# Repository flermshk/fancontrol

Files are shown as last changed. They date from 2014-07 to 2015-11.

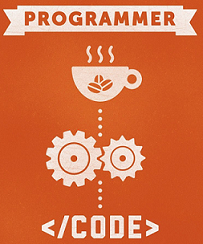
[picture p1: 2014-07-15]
Firmware/programmer-needs-coffee-to-code-hd-desktop-wallpaper.png

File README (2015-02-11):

---------------------------------------
BRIEF
The Project goal is to use a Attiny13A
and a temperature sensors to control
a PC fan.

A potentiometer is used to set the max
temperature at witch the fan are at
maximum capacity.

Under 25°C the fan stay off and the
power pin is also turned off.

Between 25°C and the max_temperature
the fan pwm folow a linear curve.

When selecting the max temperature
the led will blink for each 10°C
increment.

The pin refered as Reg_control or
power control is used to enable an step-up
power supply if no 12v is available.

---------------------------------------
PART REQUIREMENT

[Temperature IC]
Manufacturer: Texas Instrument
Part name	: LMT90DBZT
Footprint	: SOT23-3 / TO-236-3 / SC-59
Digi-Key	: 296-35732-1-ND
Price (x1)	: 1.18
Price (x10)	: 9.73
http://www.digikey.ca/product-search/en?KeyWords=296-35732-1-ND

[Micro-controler]
Manufacturer: Atmel
Part name	: ATTINY13A
Footprint	: 8-SOIC / 8-PDIP
Digi-Key	: ATTINY13A-SNRCT-ND / ATTINY13A-PU-ND
Price (x1)	: 1.66
Price (x10)	: 14.75
http://www.digikey.ca/product-detail/en/ATTINY13A-SNR/ATTINY13A-SNRCT-ND/3440990

---------------------------------------
ATTiny13A PINOUT
						  ___
(PCINT5/RST/ADC0/dW) PB5-|*	 |-VCC	[2:5] V.
(PCINT3/CLKI/ADC3)	 PB3-|	 |-PB2	(SCK/ADC1/T0/PCINT2)
(PCINT4/ADC2)		 PB4-|	 |-PB1	(MISO/AIN1/OC0B/INT0/PCINT1)
					 GND-|___|-PB0	(MOSI/AIN0/OC0A/PCINT0)
memory:
	1KB Flash
	64B SRAM
	64B EEMPROM

---------------------------------------
DESCRIPTION

Port	Tris		- ALT	- Role
- - - - - - - - - - - - - -
PB0	 - Output	- OC0A	- PWM (fan control)
PB1	 - Output	-		- Reg_control (on/off)
PB2	 - Output	-		- LED (alarm)
PB3	 -			- ADC3	- potentiometer
PB4	 -			- ADC2	- temp sensor
PB5	 - 			- dont	- touch

---------------------------------------
ABOUT
Author: Jonathan.L
Contributor: Laurence.DV

Original 14/06/2014
Update	25/07/2014

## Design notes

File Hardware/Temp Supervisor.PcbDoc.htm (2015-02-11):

Altium Reporting Options

# File in Newer Format

Date | : | 05/09/2014
Time | : | 19:48:47
Filename | : | C:\work\fancontrol\Hardware\Temp Supervisor.PcbDoc

Version | Warning
Release 10 update 1 | CAUTION - New Clearance Rule subscopes targeting differential pairs were introduced. Be aware that your design might contain Clearance Rules using those subscopes that cannot be read in previous versions.
Release 10 update 15 | CAUTION - Support of Solder Mask and Paste Mask expansions for Tracks, Arcs, Fills and Regions was introduced. Be aware that your design might contain Solder Mask and Paste Mask expansions for these types of primitives that cannot be read in the version of Altium Designer you are currently using.
Altium Designer update 19 | CAUTION - Air Gap Width attribute was introduced to Polygon Connect Style Rule. Be aware that your design might contain Polygon Connect Style Rules with new Air Gap Width attribute cannot be read in the version of Altium Designer you are currently using.
Release 13 | CAUTION - Silk To Solder Mask Clearance Rules are converted to Silkscreen Over Component Pads Rules.

This file was generated by a later version of the software

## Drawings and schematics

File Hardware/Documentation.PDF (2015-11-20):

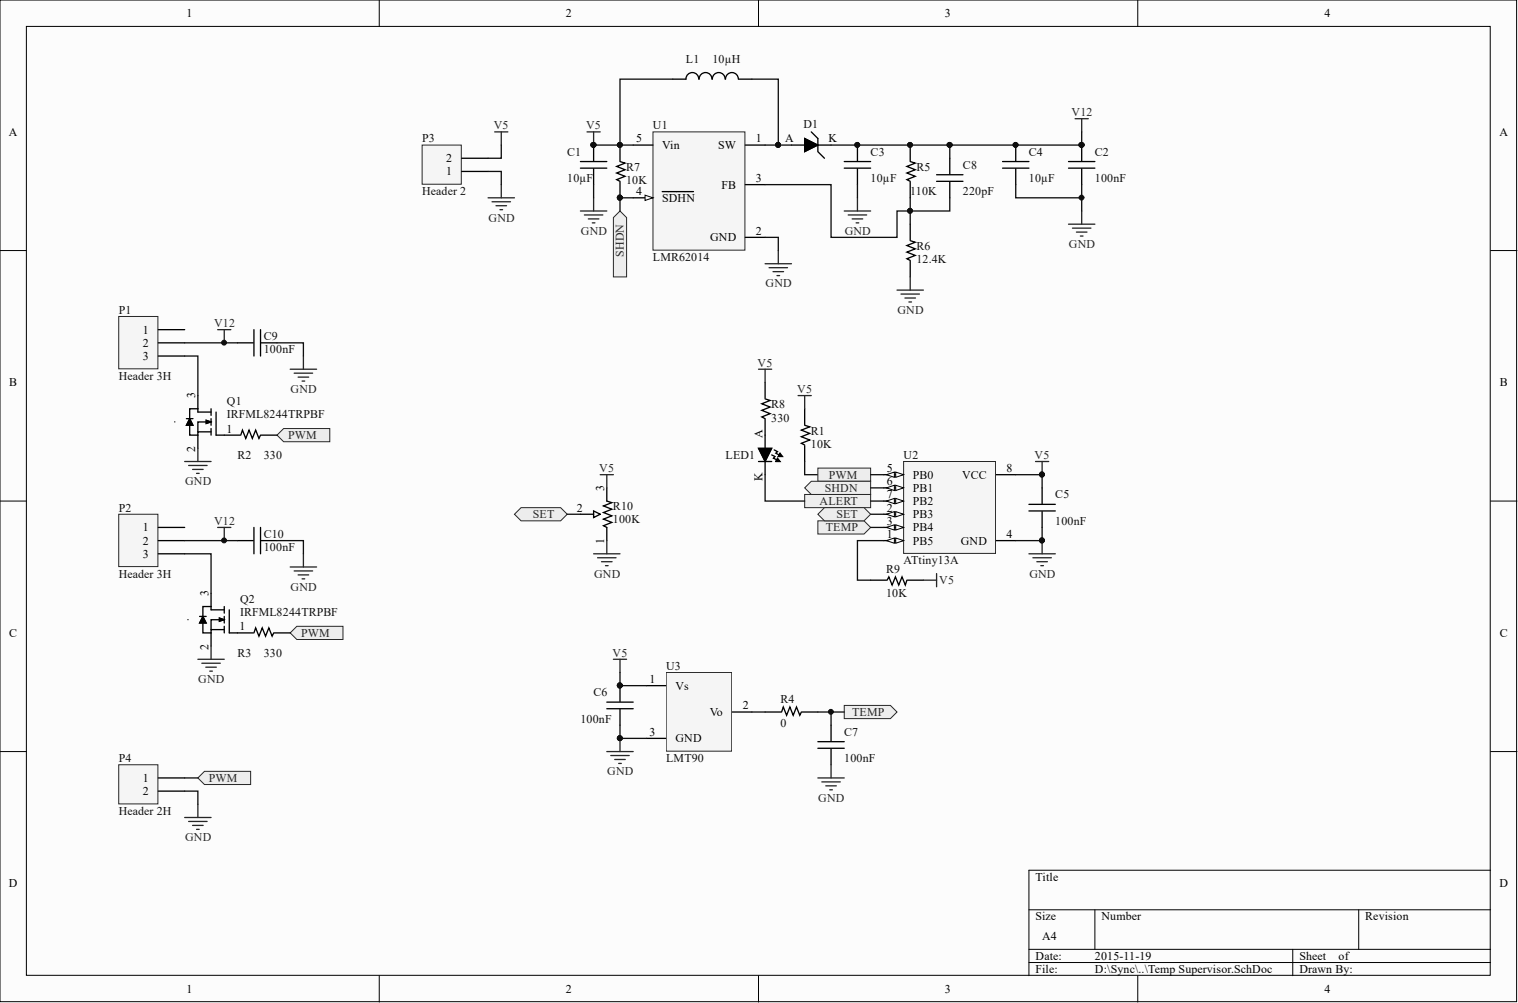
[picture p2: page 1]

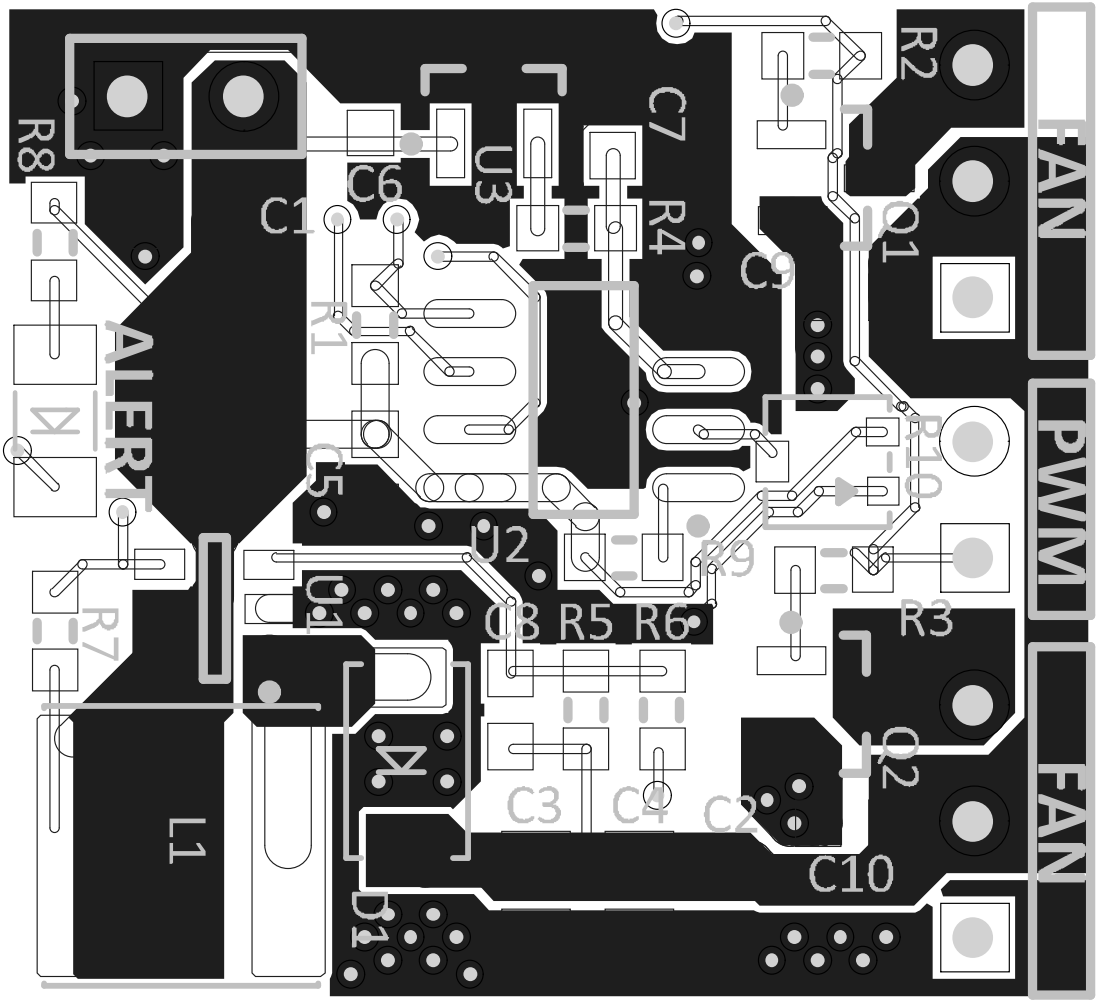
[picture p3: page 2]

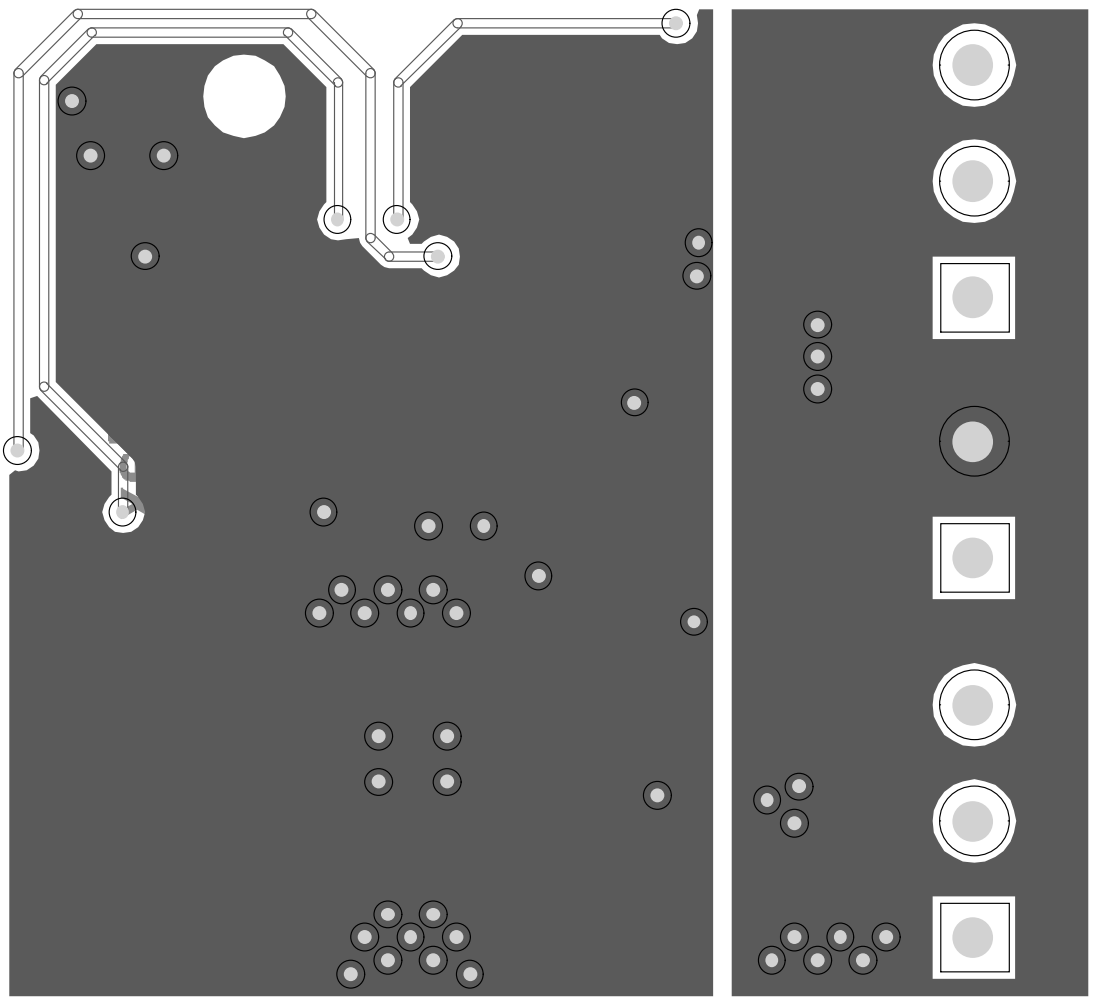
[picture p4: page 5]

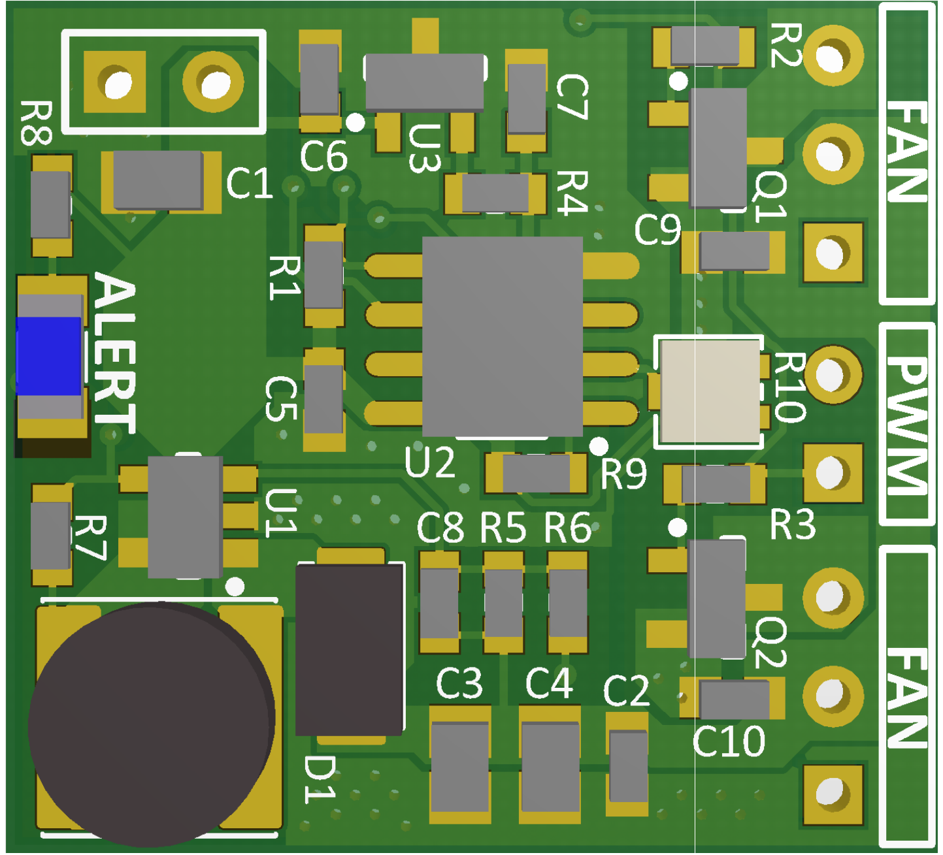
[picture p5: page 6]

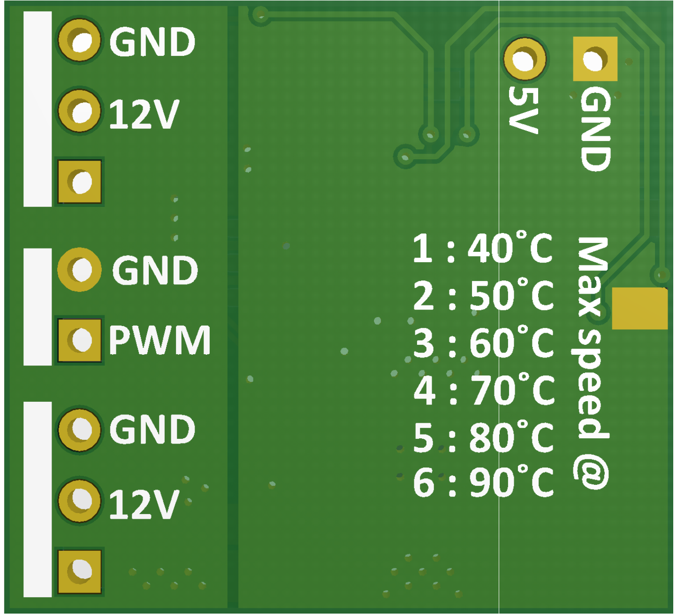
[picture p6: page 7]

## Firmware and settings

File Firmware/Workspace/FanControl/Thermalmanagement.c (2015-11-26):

/**																		  ___
	@File	: Thermalmanagement.c				(PCINT5/RST/ADC0/dW) PB5-|*	 |-VCC	[2:5] V.							Spec
	@project: Smart fan controller				(PCINT3/CLKI/ADC3)	 PB3-|	 |-PB2	(SCK/ADC1/T0/PCINT2)				1KB Flash
	@Brief	: Programmable fan controller		(PCINT4/ADC2)		 PB4-|	 |-PB1	(MISO/AIN1/OC0B/INT0/PCINT1)		64B SRAM
	@Hardware ATtiny13A												 GND-|___|-PB0	(MOSI/AIN0/OC0A/PCINT0)				64B EEPROM
							  
	Port   Tris		- ALT	- Role
	- - - - - - - - - - - - - - 
	PB0	 - Output	- OC0A	- PWM (fan control) [@25KHz]
	PB1	 - Output	-		- Reg_control (on/off)
	PB2	 - Output	-		- LED (alarm) 
	PB3	 -			- ADC3	- potentiometer
	PB4	 -			- ADC2	- temp sensor
	PB5	 - 			- dont	- touch

	Temperature IC: LMT90DBZT OR MCP9701A	

	@Author: Jonathan L'Espérance
	@Original 14/06/2014
	@Update	25/07/2014
*/

 /*************************\
 | Compilation time option |
 \*************************/

#define PWM_VAL_MIN		0x19	//Minimum PWM value	[0:FF]
#define PWM_VAL_MAX		0xFF	//Maximum PWM value	[0:FF]
#define TEMP_VAL_START	25		//Temperature to start Fan power[0:100] °C 
#define TEMP_VAL_MAX	100		//Maximum temperature the user can set the Max_temp

#define PCB_REV_A
//#define PCB_REV_B

//Temperature sensors selection
#define LMT90DBZT
//#define MCP9701A
 
//Uncomment if applicable
#define PWM_ACTIVE_LOW		
//#define FAN_POWER_ACTIVE_LOW
#define ALERT_ACTIVE_LOW


 /**********\
 | Includes |
 \**********/

#define F_CPU 1000000UL  // 1 MHz => usefull for delay
#include <stdint.h>
#include <stdlib.h>

#include <avr/eeprom.h>
#include <avr/interrupt.h>
#include <avr/io.h>
#include <avr/pgmspace.h>
#include <avr/sleep.h>
#include <avr/wdt.h>
#include <util/delay.h>


 /********************\
 | MACRO and shortcut |
 \********************/

#define MUX_POT_CHAN	0x23	//(ADMUX = (1<< ADLAR) | 0x02)//ADC3	PB3
#define MUX_TEMP_CHAN	0x22	//(ADMUX = (1<< ADLAR) | 0x03)//ADC2	PB4

//ADC Conversion Done
#define AdcConvDone		((ADCSRA & (1 << ADSC)) == 0)

//fan power control [on/ off]
#ifdef FAN_POWER_ACTIVE_LOW
	#define fan_power_on() 		(PORTB	&= ~(1<<PORTB1))
	#define fan_power_off() 	(PORTB	|=  (1<<PORTB1))
#else
	#define fan_power_off() 	(PORTB	&= ~(1<<PORTB1))
	#define fan_power_on() 		(PORTB	|=  (1<<PORTB1))
#endif

//Alert Led macro
#ifdef ALERT_ACTIVE_LOW  
	#define led_on() 		(PORTB	&= ~(1<<PORTB2))
	#define led_off() 		(PORTB	|=  (1<<PORTB2))
#else
	#define led_off() 		(PORTB	&= ~(1<<PORTB2))
	#define led_on() 		(PORTB	|=  (1<<PORTB2))
#endif

 /************\
 | Prototypes |
 \************/

//Blink the led to tell user max temperature allowed (step of 10°C)
void blink(unsigned int numbers);

//Initialize register required for the application
void ioinit (void);

//Read temperature ADC and return value in °C
void ReadTemperature(void);

//Read pot ADC and return value between [0:100]
void ReadPot(void);

//return the PWM value for actual temperature
int LinearPwmCalculate(void);

//Global Variable
unsigned int temperature		=0;		// Actual temperature in °C
unsigned int temperature_max	=0;		// user selected max allowed temperature

int main(void)
{
	int temperature_max_mem	=0;		// last temperature_max_mem
	int switch_adc			=0;		// ADC channel change flag

	_delay_ms(1000);
	
	ioinit();	//initialize all IO
  	
	while(1)
	{
		  /////////////////
		 // ADC Reading //
		/////////////////

		//If last ADC conversion is done			
		if(AdcConvDone)
		{	
			
			//select next adc reading channel (read 3x temp for each pot read
			switch_adc++;
			switch_adc &= 0x03;

			switch(switch_adc)
			{
				case 0:		ReadTemperature();	break;
				case 1:		ReadTemperature();	break;
				case 2:		ReadTemperature();	ADMUX = MUX_POT_CHAN;	break;
				case 3:		ReadPot();			ADMUX = MUX_TEMP_CHAN;	break;	
				default:	switch_adc=0;		ADMUX = MUX_TEMP_CHAN;	break; 
			}
			//start new conversion
			ADCSRA |= (1<< ADSC);			
		}
	   

		  ////////////////////////////////////////
		 // Set the maximum allowed temperature//
		////////////////////////////////////////

		//if user selected a new value
		//The led turn off for 1 sec and
		//then blink for each 10°C increment
		//ex: 5 blink = 50°C 
		//to keep if from continuously changing,
		//the new value must be 8°C more than 
		//the old value to change the value
		if((temperature_max>>1) != temperature_max_mem)
		{
			temperature_max_mem = temperature_max>>1;
			led_off();
			_delay_ms(1000);
			
			#ifdef PCB_REV_A 
				blink((temperature_max/10)-3);
			#else
				blink(temperature_max/10);
			#endif
				
			_delay_ms(1000);
		}
		
  
		  ///////////////////
		 // PWM adjusting //
		/////////////////// 

		if(temperature >= temperature_max)
		{
			fan_power_on();
			led_on();

			#ifdef PWM_ACTIVE_LOW
				OCR0A =  0xFF-PWM_VAL_MAX;
			#else
				OCR0A =  PWM_VAL_MAX;
			#endif	
		}
		else
		{ 
			led_off();
			if (temperature<=TEMP_VAL_START)
			{
				fan_power_off();
				
				#ifdef PWM_ACTIVE_LOW
					OCR0A = 0xFF;
				#else
					OCR0A = 0x00;
				#endif
				
			} 
			else
			{	
				fan_power_on();
				
				#ifdef PWM_ACTIVE_LOW
					OCR0A = 0xFF-LinearPwmCalculate();
				#else
					OCR0A = LinearPwmCalculate();	
				#endif			
			}
		}				
	}
}


//Blink the led to tell user max temperature allowed (step of 10°C)
void blink(unsigned int numbers){
	while(numbers--){
		led_on();
		_delay_ms(200);
		led_off();
		_delay_ms(200);
	}
}

//Initialize register required for the application
void ioinit (void){

	////////////////////////////////////////////////////////////////////////////
	//General I/O
	DIDR0 	=(1<<AIN0D)	|(1<<AIN1D)	|(1<<ADC1D)	|(1<<ADC3D)	|(1<<ADC2D)	|(1<<ADC0D);
	DDRB 	=(1<<DDB0)	|(1<<DDB1)	|(1<<DDB2);

	////////////////////////////////////////////////////////////////////////////
	//ADC
	ADCSRA	=  (1<<ADPS1)	|(1<<ADPS0)	|(1<<ADEN);
	ADMUX	= MUX_POT_CHAN;

	////////////////////////////////////////////////////////////////////////////
	//EEPROM
	//EEPROM Control Register
	//EECR 	=(0<<EERE)	|(0<<EEWE)	|(0<<EEMWE)	|(0<<EERIE)	|(0<<EEPM0)	|(0<<EEPM1);
	//EEPROM Data Register
	//EEDR 	=0;
	//EEPROM Address Register
	//EEARL	= 0;

	////////////////////////////////////////////////////////////////////////////
	//Timer / PWM
	TCCR0A 	=(1<<WGM01)|(1<<WGM00)|(1<<COM0A1)|(1<<COM0A0);
	OCR0A 	= 0;
	TCCR0B 	=(0<<CS02)|(0<<CS01)|(1<<CS00);//|   (1<<WGM02);		//gm02 toggle pwm
}

void ReadTemperature(void)
{
	
	#ifdef LMT90DBZT
		temperature= (ADCH-25)<<1;
	#endif

	#ifdef MCP9701A
		temperature = ADCH-20;	
	#endif
	
}

//return pot value [0:100]
void ReadPot(void)
{
	unsigned int temp;

	
	#ifdef PCB_REV_A 
		/*
		rev A blink per temp max
			1: 40˚C 
			2: 50˚C
			3: 60˚C
			4: 70˚C
			5: 80˚C
			6: 90˚C
		*/
		temp= ADCH>>5; // [0:255]>>5 => [0:7]
		temp*=10;	   // [0:7] *10  => [0:70]
		temp+=40;	   // [0:70] +40 => [40:110]

		if(temp>90)
			temperature_max= 90;
		else
			temperature_max= temp;
			
	#else
		/*rev B blink per temp max
			1x per 10°C increment
			1:10 °C
			2:20 °C
			(...)
			5:50 °C
			(...)
			10:100 °C
		*/

		temp= ADCH/2;

		if(temp>TEMP_VAL_MAX)
			temperature_max= TEMP_VAL_MAX;
		else
			temperature_max= temp;
	#endif

	
}


//The pwm linearisation formulae is
//pwm = (temperature-temp_start) * (PWM_MAX-PWM_Min) / (temperature_max-temp_start) + PWM_Min
int LinearPwmCalculate(void)
{
	double temp_math;
	
//	temp_math  = ( temperature - TEMP_VAL_START);
//	temp_math *= ( PWM_VAL_MAX - PWM_VAL_MIN);
//	temp_math /= ( temperature_max - TEMP_VAL_START);
//	temp_math += ( PWM_VAL_MIN);

	temp_math  = ( temperature - TEMP_VAL_START)*( PWM_VAL_MAX - PWM_VAL_MIN) /  ( temperature_max - TEMP_VAL_START)+ ( PWM_VAL_MIN);


	//Should never be greater than 0xFF from my calculation
	if(temp_math>= 0xFF)
		return 0xFF;

	return ((unsigned int) temp_math);
}

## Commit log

2014-07-15 test de configuration et ajout du logo du group OpIUM new file: programmer-needs-coffee-to-code-hd-desktop-wallpaper.png
2014-07-26 Retrait du Look-up table. Création d'une fonction de linearisation pour pwm selon le maximum défini par l'utilisateur et les paramètre de compilation en tête de documents ----------------------------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
2014-07-26 Fix de bug, version fonctionnel, probablement Finale 75% PROGMEM USED
    [Thermalmanagement.c]
2014-07-28 Added Max temperature setting for PCB_REV_A Blink per temperature 1: 40˚C 2: 50˚C 3: 60˚C 4: 70˚C 5: 80˚C 6: 90˚C modified: Thermalmanagement.c
2014-08-01 Verification of previous modification, Added compatibility for MCP9701A (temperature sensors)
    All is working perfectly
2014-09-03 +ADD Hardware design file #MOD folder struct reorganized for seperating FW and HW
    [Temp Supervisor.PcbDoc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]
2014-09-10 #MOD Finalized values for DC/DC Passives
    [Temp Supervisor.PrjPCB, Temp Supervisor.SchDoc]
2015-02-11 New server
    [Temp Supervisor.PrjPCB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]
